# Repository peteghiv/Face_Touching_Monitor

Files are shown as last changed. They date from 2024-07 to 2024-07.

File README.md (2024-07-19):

# Face Touching Monitor

## Video Demo
[Face Touching Monitor Demo](https://drive.google.com/file/d/1w5yBVgI8V5LmS3UyNFrMT8TmZ0G51bC_/view?usp=drive_link)

## Background
This project was completed under Science Centre Singapore CRADLE lab's Research and Development Experience Programme (RDEP), it was completed in a total of 8 working days, spread out from Feb-May 2022.

In a time when COVID-19 cases were running rampant, personal hygiene became all the more important to limit the spread of COVID. However, people may still unknowingly be touching their faces due to subconscious habits. This project therefore proposes a prototype of a wearable solution to nudge users who are about to touch their face.

## Products used
1. Arduino Nano
2. RF Transmitter & Receiver
3. Ultrasonic Sensors
4. Servo Motors

## Setting Up Wiring (Transmitter)
### RF Transmitter
1. VCC: 5V supply
2. GND: Ground
3. DATA: Pin 2

### Ultrasonic Sensor 1
1. VCC: 5V supply
2. GND: Ground
3. ECHO: Pin 4
4. TRIG: Pin 5

### Ultrasonic Sensor 2
1. VCC: 5V Supply
2. GND: Ground
3. ECHO: Pin 6
4. TRIG: Pin 7

### Battery Pack
1. Red Wire: 5V
2. Black Wire: Ground

## Setting Up Wiring (Receiver)
### RF Receiver
1. VCC: 5V Supply
2. GND: Ground
3. DATA: Pin 2

### Servo Motor
1. VCC: 5V Supply
2. GND: Ground
3. SIGNAL: Pin 10

### Battery Pack
1. Red Wire: Vin
2. Black Wire: Ground

## Maintenance
### Changing Batteries (Transmitter)
1. Remove duct tape connecting transmitter to cap.
2. Remove tape holding the box together, the box should open. If not, gently remove one of the sides.
3. Replace batteries (3 × 1.5V) as required.
4. Put the box back together and tape as needed.

### Changing Batteries (Receiver)
1. Locate the top of housing (side with the slit)
2. Use a flat-head screwdriver to gently pry open the top of the housing. *Pry from the sides to prevent damage to the acrylic*.
3. Replace batteries (3 × 1.5V) as required.
4. Put the box back together, *ensuring that the slit is in the right position* for the elliptical cutout.

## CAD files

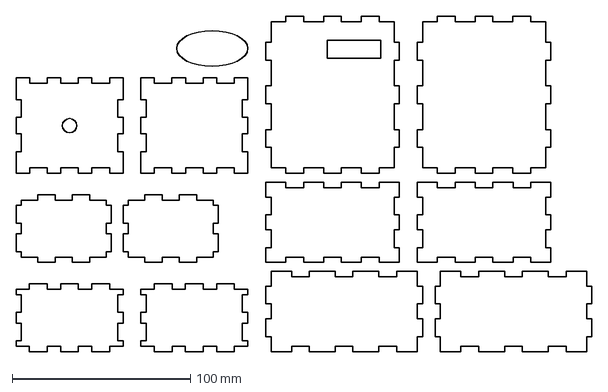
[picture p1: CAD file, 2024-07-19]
housing_for_electronics.dxf
323.0 x 188.0 mm

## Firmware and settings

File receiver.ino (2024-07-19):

/*
-------------------------------------------------------------------------------------
Receiver Code
-------------------------------------------------------------------------------------
*/


// Include necessary libraries for RadioHead
#include <RH_ASK.h>
#ifdef RH_HAVE_HARDWARE_SPI
  #include <SPI.h>
#endif

// Include necessary libraries for Servo
#include <ServoTimer2.h>

// Servo Motor on pin 10
const int servopin = 10;
ServoTimer2 myservo;

// RF Receiver (Set to Pin 2)
RH_ASK driver(1000, 2, 4, 0);

void setup()
{
    // Set-up RF Receiver
    #ifdef RH_HAVE_SERIAL
      Serial.begin(115200);    
    #endif
    if (!driver.init())
      #ifdef RH_HAVE_SERIAL
         Serial.println("init failed");
      #else;
      #endif

    // Set-up Servo Motor
    myservo.attach(servopin);
    myservo.write(750);
}

void loop()
{
    // Generate array to receive data
    uint8_t buf[3];
    uint8_t buflen = sizeof(buf);
    // Receive message
    if (driver.recv(buf, &buflen)) driver.printBuffer("Got:", buf, buflen);
    
    // Convert message to ASCII characters
    String ans = "";
    for (int i = 0; i < 3; ++i) ans += (char)buf[i];
    
    // Turn Servo Motor if the message received is "pos"
    if (ans == "pos")
    {
      for (int i = 1750; i > 750; i -= 50)
      {
        myservo.write(i);
        delay(15); 
      }
      delay(150);
      for (int i = 750; i < 1750; i += 50)
      {
        myservo.write(i);
        delay(15);
      }
      delay(150);
    }
}

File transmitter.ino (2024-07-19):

/*
-------------------------------------------------------------------------------------
Transmitter Code

microsecondsToCentimeters converts the travel time (μs) of an ultrasonic wave to half
of the distance it has covered (cm). This effectively obtains the distance between an
ultrasonic sensor and an object.

getDist1 & getDist2 get the distance (cm) of an object from each ultrasonic sensor
-------------------------------------------------------------------------------------
*/

// Import necessary libraries for RadioHead
#include <RH_ASK.h>
#ifdef RH_HAVE_HARDWARE_SPI
  #include <SPI.h> 
#endif

// Trig & Echo Pins for US Sensor
const int trigPin1 = 5;
const int echoPin1 = 4;
const int trigPin2 = 7;
const int echoPin2 = 6;

// RF Transmitter (Set to Pin 2)
RH_ASK driver(1000, 4, 2, 0); 

void setup()
{
    // Set-up RF Transmitter
    #ifdef RH_HAVE_SERIAL
      Serial.begin(115200);   
    #endif
    if (!driver.init())
      #ifdef RH_HAVE_SERIAL
        Serial.println("init failed");
      #else;
      #endif

    // Set up US Sensors
    pinMode(trigPin1, OUTPUT);
    pinMode(echoPin1, INPUT);
    pinMode(trigPin2, OUTPUT);
    pinMode(echoPin2, INPUT);
}

void loop()
{
    // Define messages to be sent
    const char * positive = "pos";
    const char * negative = "neg";

    // Obtain distances and send the appropriate message
    int distance1 = getDist1();
    int distance2 = getDist2();
    if (distance1 <= 10 && distance2 <= 10)
    {
      driver.send((uint8_t *)positive, strlen(positive));
      driver.waitPacketSent();
      delay(700);
    }
    else
    {
      driver.send((uint8_t *)negative, strlen(negative));
      driver.waitPacketSent();
      delay(700);
    }
}

long microsecondsToCentimeters(long microseconds) {
   return microseconds / 29 / 2;
}

int getDist1()
{
   long duration, cm;

   // Send pulse from transmitter
   digitalWrite(trigPin1, LOW);
   delayMicroseconds(2);
   digitalWrite(trigPin1, HIGH);
   delayMicroseconds(10);
   digitalWrite(trigPin1, LOW);

   // Get travel time between sensor and object, then convert to distance
   duration = pulseIn(echoPin1, HIGH);
   cm = microsecondsToCentimeters(duration);
   return (int) cm;
}

int getDist2()
{
   long duration, cm;

   // Send pulse from transmitter
   digitalWrite(trigPin2, LOW);
   delayMicroseconds(2);
   digitalWrite(trigPin2, HIGH);
   delayMicroseconds(10);
   digitalWrite(trigPin2, LOW);

   // Get travel time between sensor and object, then convert to distance
   duration = pulseIn(echoPin2, HIGH);
   cm = microsecondsToCentimeters(duration);
   return (int) cm;
}
